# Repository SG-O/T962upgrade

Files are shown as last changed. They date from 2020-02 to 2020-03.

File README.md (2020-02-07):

**WARNING** This is work in progress! Expect everything to be broken!

# T962upgrade | T-962/T-962A controller upgrade #

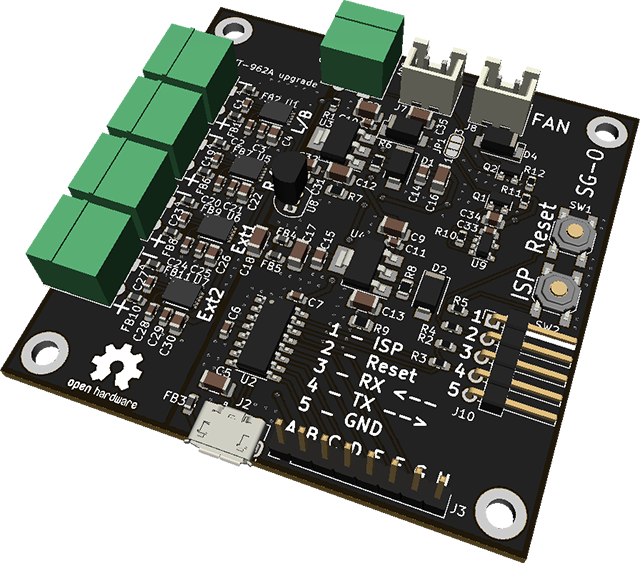
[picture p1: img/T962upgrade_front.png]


## Features ##
### CPU ###
- MAX31850 based K Type thermocouple to single wire converter
- CH340 based USB to UART
- Temperature dependant fan controller

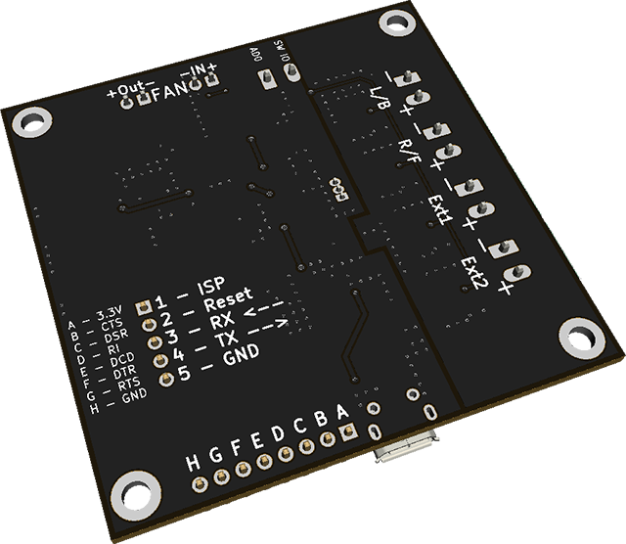
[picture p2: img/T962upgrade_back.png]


### IO ###
- 4 K Type thermocouple to single wire converter
- 1 UART
- 1 USB
- Push buttons for reset and ISP mode

### Power Supply ###
- Dual linear power supplies for digital and analog circuitry

## Software ##
This was designed for the T-962-improvements Firmware developed by UnifiedEngineering: [https://github.com/UnifiedEngineering/T-962-improvements](https://github.com/UnifiedEngineering/T-962-improvements)

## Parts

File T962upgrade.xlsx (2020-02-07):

Component | Description | Part | References | Value | Footprint | Quantity Per PCB | manf# | lcsc# | DNP
1 | Unpolarized capacitor | C | C3 C6 C7 C10 C11 C21 C25 C29 C31 C33 | 100n | C_0603_1608Metric | 10 | CC0603KRX7R9BB104 | C14663
2 | Unpolarized capacitor | C | C1 C2 C19 C20 C23 C24 C27 C28 | 10n | C_0603_1608Metric | 8 | 0603B103K500NT | C57112
3 | Unpolarized capacitor | C | C5 C8 C9 C12 C13 C16 C17 C18 C35 | 10u | C_1206_3216Metric | 9 | CL31A106KBHNNNE | C13585
4 | Unpolarized capacitor | C | C4 C14 C15 C22 C26 C30 C32 C34 | 1u | C_0805_2012Metric | 8 | CL21B105KBFNNNE | C28323
5 | Diode | D | D1 D2 D3 D4 | M7 | D_SMA | 4 | M7 | C95872
6 | Ferrite bead, small symbol | Ferrite_Bead_Small | FB1 FB2 FB3 FB4 FB5 FB6 FB7 FB8 FB9 FB10 FB11 | Ferrite_Bead_Small | L_0603_1608Metric | 11 | BLM18PG121SN1D | C14709
7 | Generic connector, single row, 01x02, script generated (kicad-library-utils/schlib/autogen/connector/) | Conn_01x02 | J7 | Fan In | JST_XH_B2B-XH-A_1x02_P2.50mm_Vertical | 1 | B2B-XH-A(LF)(SN) | C158012
8 | Generic connector, single row, 01x02, script generated (kicad-library-utils/schlib/autogen/connector/) | Conn_01x02 | J8 | Fan Out | JST_XH_B2B-XH-A_1x02_P2.50mm_Vertical | 1 | B2B-XH-A(LF)(SN) | C158012
9 | Generic screw terminal, single row, 01x02, script generated (kicad-library-utils/schlib/autogen/connector/) | Screw_Terminal_01x02 | J1 J4 J5 J6 J9 | K Type | PhoenixContact_MC_1,5_2-G-3.81_1x02_P3.81mm_Horizontal | 5 | WJ15EDGRC-3.81-2P | WJ15EDGK-3.81-2P | C8387 | C8466
10 | Generic connector, single row, 01x05, script generated (kicad-library-utils/schlib/autogen/connector/) | Conn_01x05_Male | J10 | UART | PinHeader_1x05_P2.54mm_Horizontal | 1 | MTB125-1105R1 | C376123
11 | USB Micro Type B connector | USB_B_Micro | J2 | USB_B_Micro | USB_Micro-B_Molex-105017-0001 | 1 | 105017-0001 | C136000
12 | Generic connector, single row, 01x08, script generated (kicad-library-utils/schlib/autogen/connector/) | Conn_01x08_Male | J3 | USB_X | PinHeader_1x08_P2.54mm_Vertical | 1 |  |  | DNP
13 | 3-pole Solder Jumper, pins 1+2 closed/bridged | SolderJumper_3_Bridged12 | JP1 | Jumper_Fan | SolderJumper-3_P1.3mm_Bridged12_RoundedPad1.0x1.5mm_NumberLabels | 1 |  |  | DNP
14 | N-MOSFET transistor, gate/source/drain | Q_NMOS_GSD | Q1 Q2 | 2N7002 | SOT-23 | 2 | 2N7002 | C8545
15 | Resistor | R | R11 R12 | 100k | R_0603_1608Metric | 2 | 0603WAF1003T5E | C25803
16 | Resistor | R | R6 R8 | 237R | R_0805_2012Metric | 2 | ARG05FTC2370N | C218442
17 | Resistor | R | R7 R9 | 383R | R_0805_2012Metric | 2 | ARG05FTC3830 | C218541
18 | Resistor | R | R2 R3 R4 R5 | 470R | R_0603_1608Metric | 4 | 0603WAF4700T5E | C23179
19 | Resistor | R | R1 | 4k7 | R_0603_1608Metric | 1 | 0603WAF4701T5E | C23162
20 | Resistor | R | R10 | 52k3 | R_0603_1608Metric | 1 | ARG03FTC5232 | C218068
21 | Push button switch, generic, two pins | SW_Push | SW1 SW2 | Boot | SW_SPST_SKQG_WithStem | 2 | TS-1187A-C-C-B | C318889
22 | USB serial converter, UART, SOIC-16 | CH340G | U2 | CH340C | SOIC-16_3.9x9.9mm_P1.27mm | 1 | CH340C | C84681
23 | 1-Wire Ambient Temperature Sensor TO-92 | DS18S20 | U8 | DS18S20 | TO-92_Inline | 1 | DS18S20 | C52574
24 | 1A 35V Adjustable Linear Regulator, SOT-89/SOT-223/TO-220/TO-252/TO-263 | LM317_3PinPackage | U3 U4 | LM317_3PinPackage | SOT-223-3_TabPin2 | 2 | LM317DCYR | C51466
25 | Cold-Junction Compensated, 1-Wire Thermocouple-to-Digital Converter | MAX31850KATB | U1 U5 U6 U7 | MAX31850KATB | TDFN-10-1EP_3x4mm_Pitch0.5mm | 4 | MAX31850KATB+ | C476179
26 |  | TMP709 | U9 | TMP709 | SOT-23-5 | 1 | TMP709AIDBVR | C183087

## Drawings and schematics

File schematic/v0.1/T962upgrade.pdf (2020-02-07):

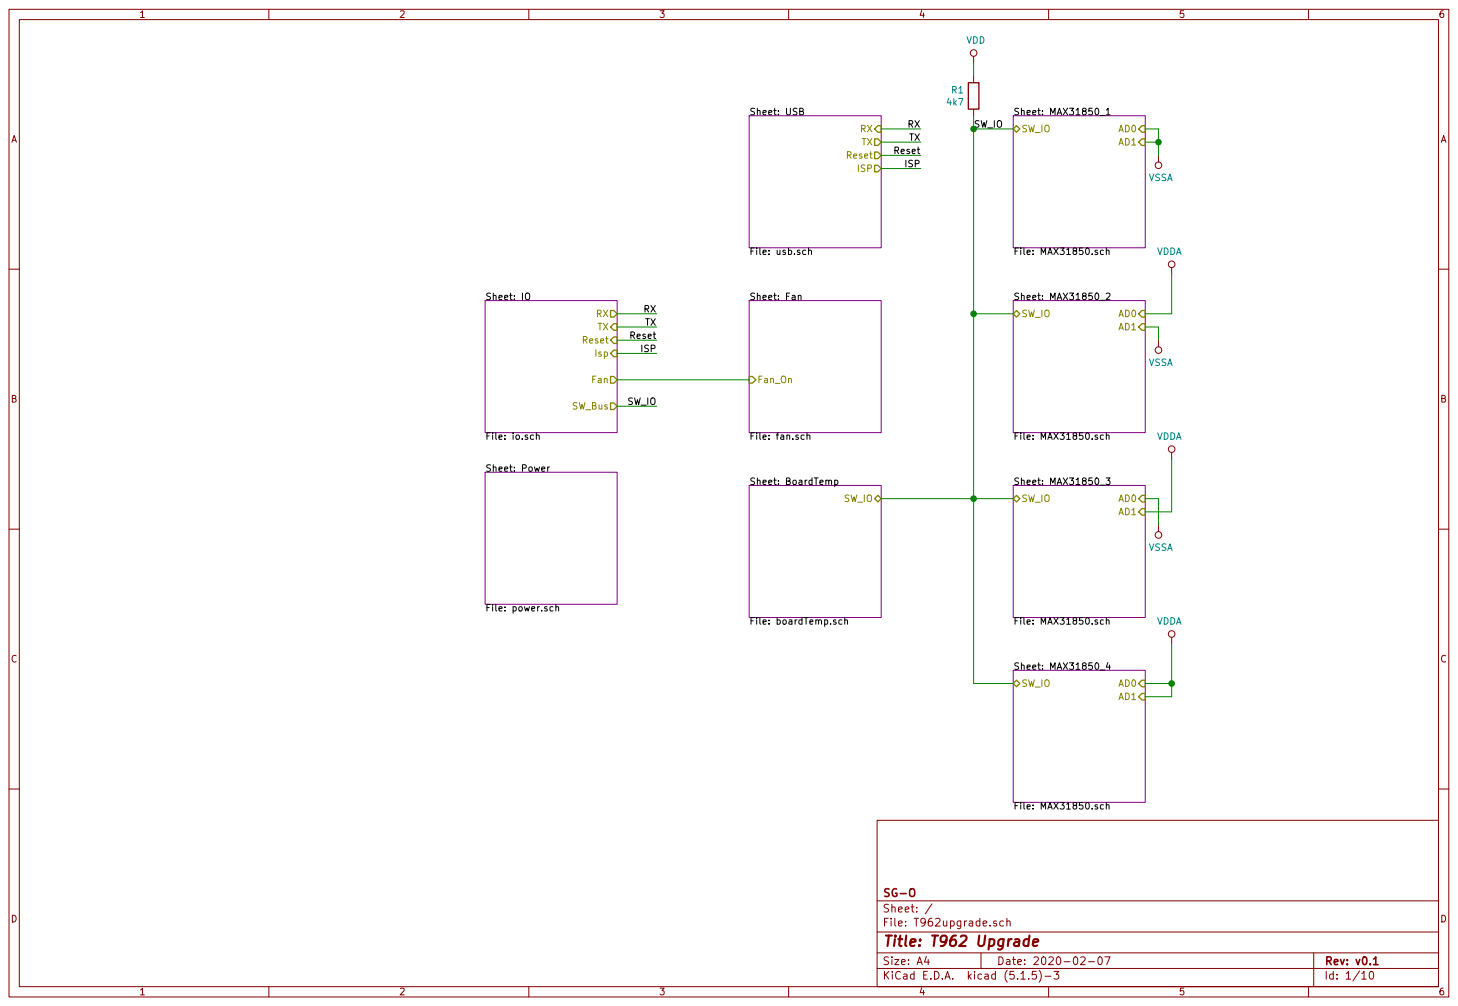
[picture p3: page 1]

Sheet: Fan File: fan.sch Fan_On Sheet: IO

File: T962upgrade.sch Sheet: / SG-O

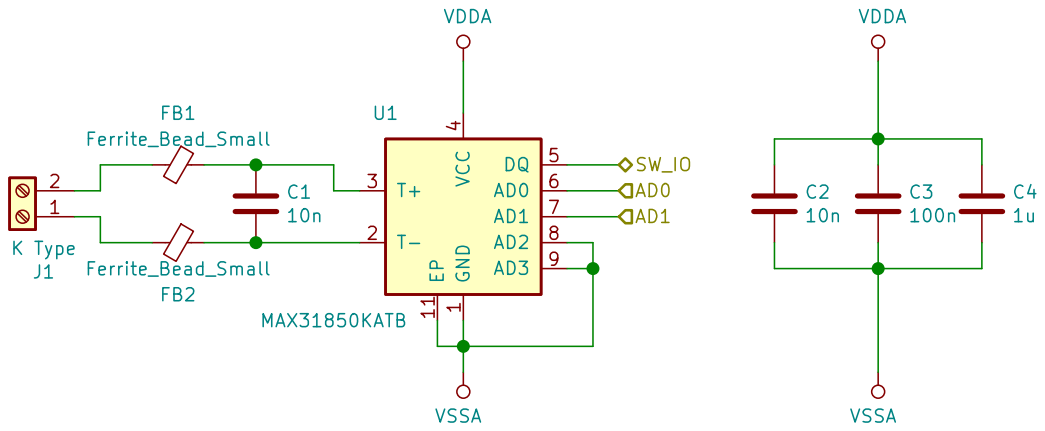
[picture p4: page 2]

File: MAX31850.sch Sheet: /MAX31850_1/ SG-O GND

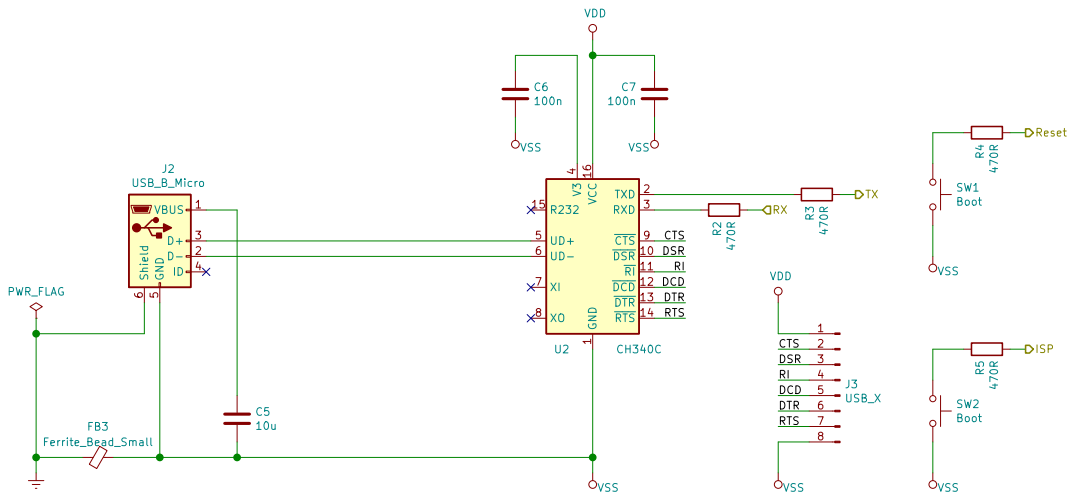
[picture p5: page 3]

1 DSR 10 RI 11 DCD 12 DTR 13 RTS 14 R232 15 VCC 16 TXD 2 RXD 3 V3

4 UD+ 5 UD- 6 XI 7 XO 8 CTS 9 U2 CH340C

File: usb.sch Sheet: /USB/ SG-O

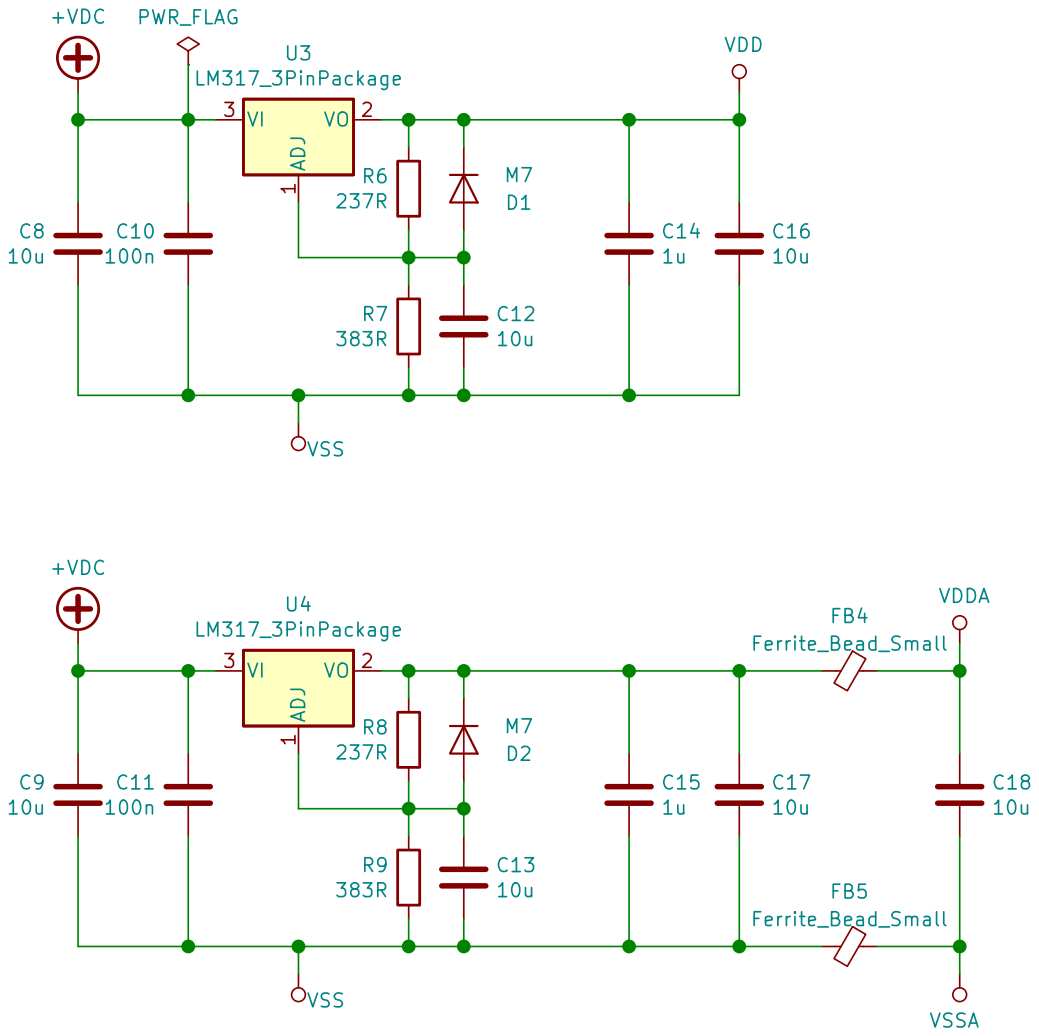
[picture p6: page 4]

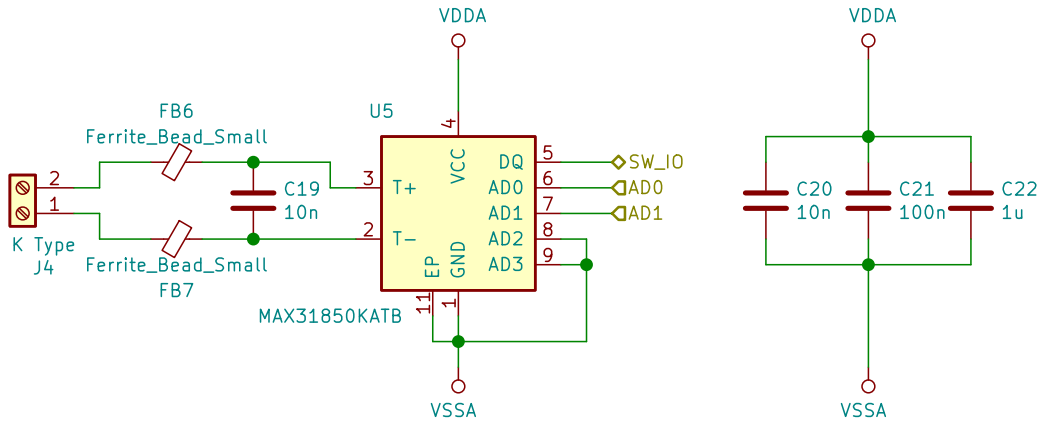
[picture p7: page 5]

File: MAX31850.sch Sheet: /MAX31850_2/ SG-O GND

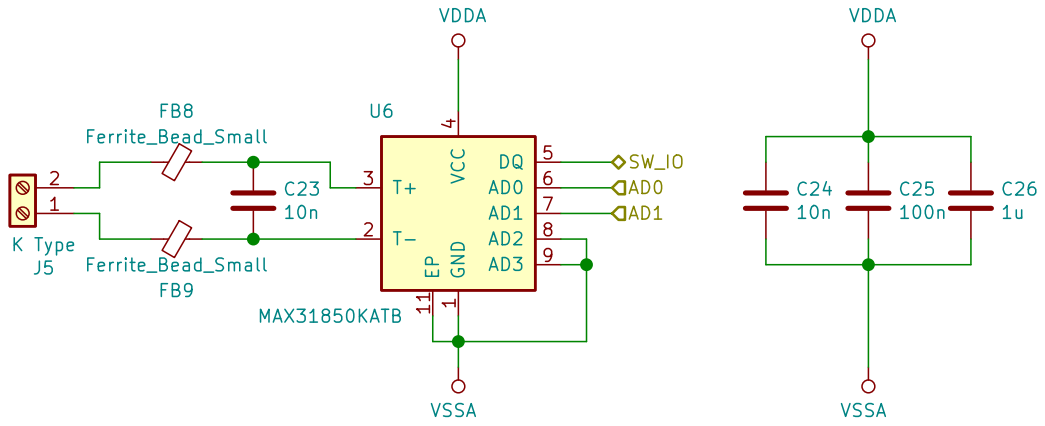
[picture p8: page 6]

File: MAX31850.sch Sheet: /MAX31850_3/ SG-O GND

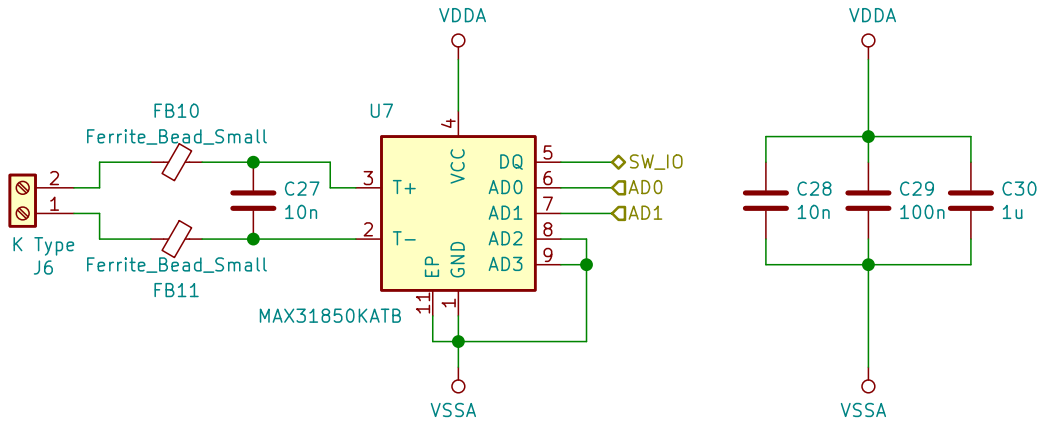
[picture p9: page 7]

File: MAX31850.sch Sheet: /MAX31850_4/ SG-O GND

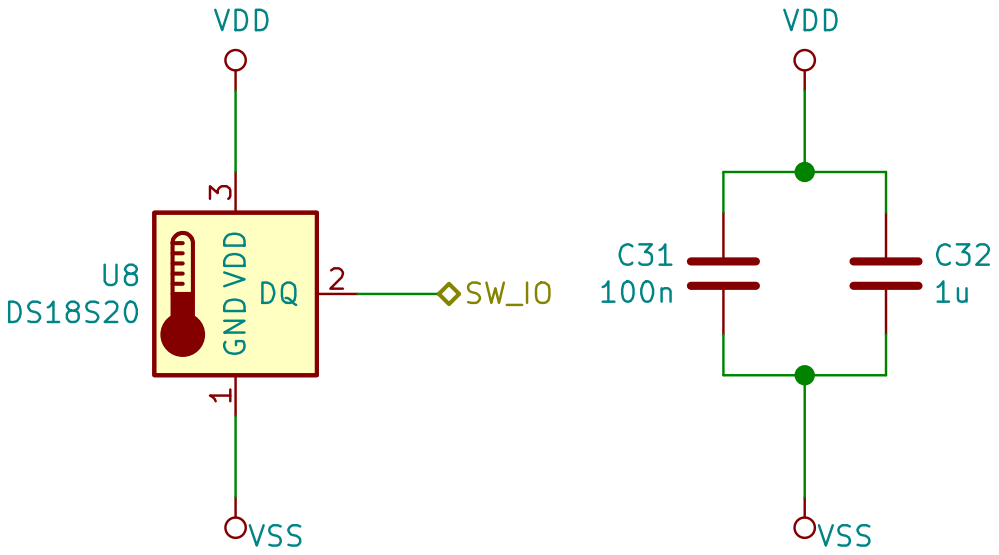
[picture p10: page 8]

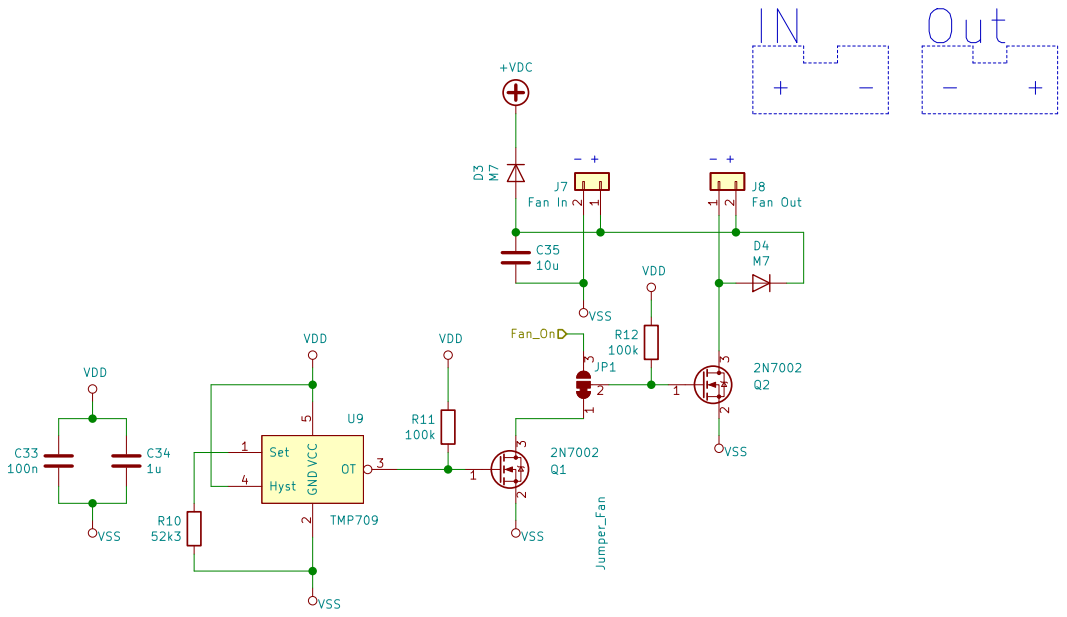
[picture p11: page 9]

File: fan.sch Sheet: /Fan/ SG-O

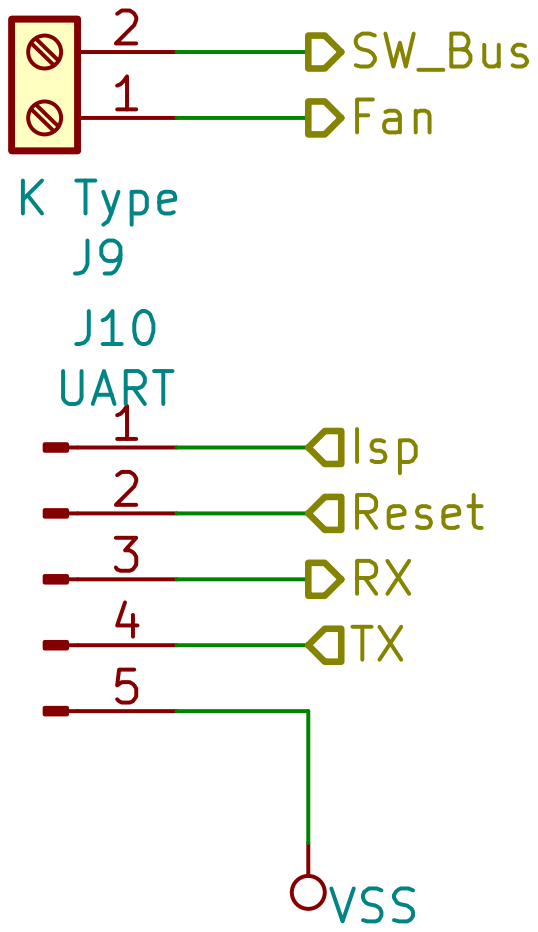
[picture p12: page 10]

File: io.sch Sheet: /IO/ SG-O

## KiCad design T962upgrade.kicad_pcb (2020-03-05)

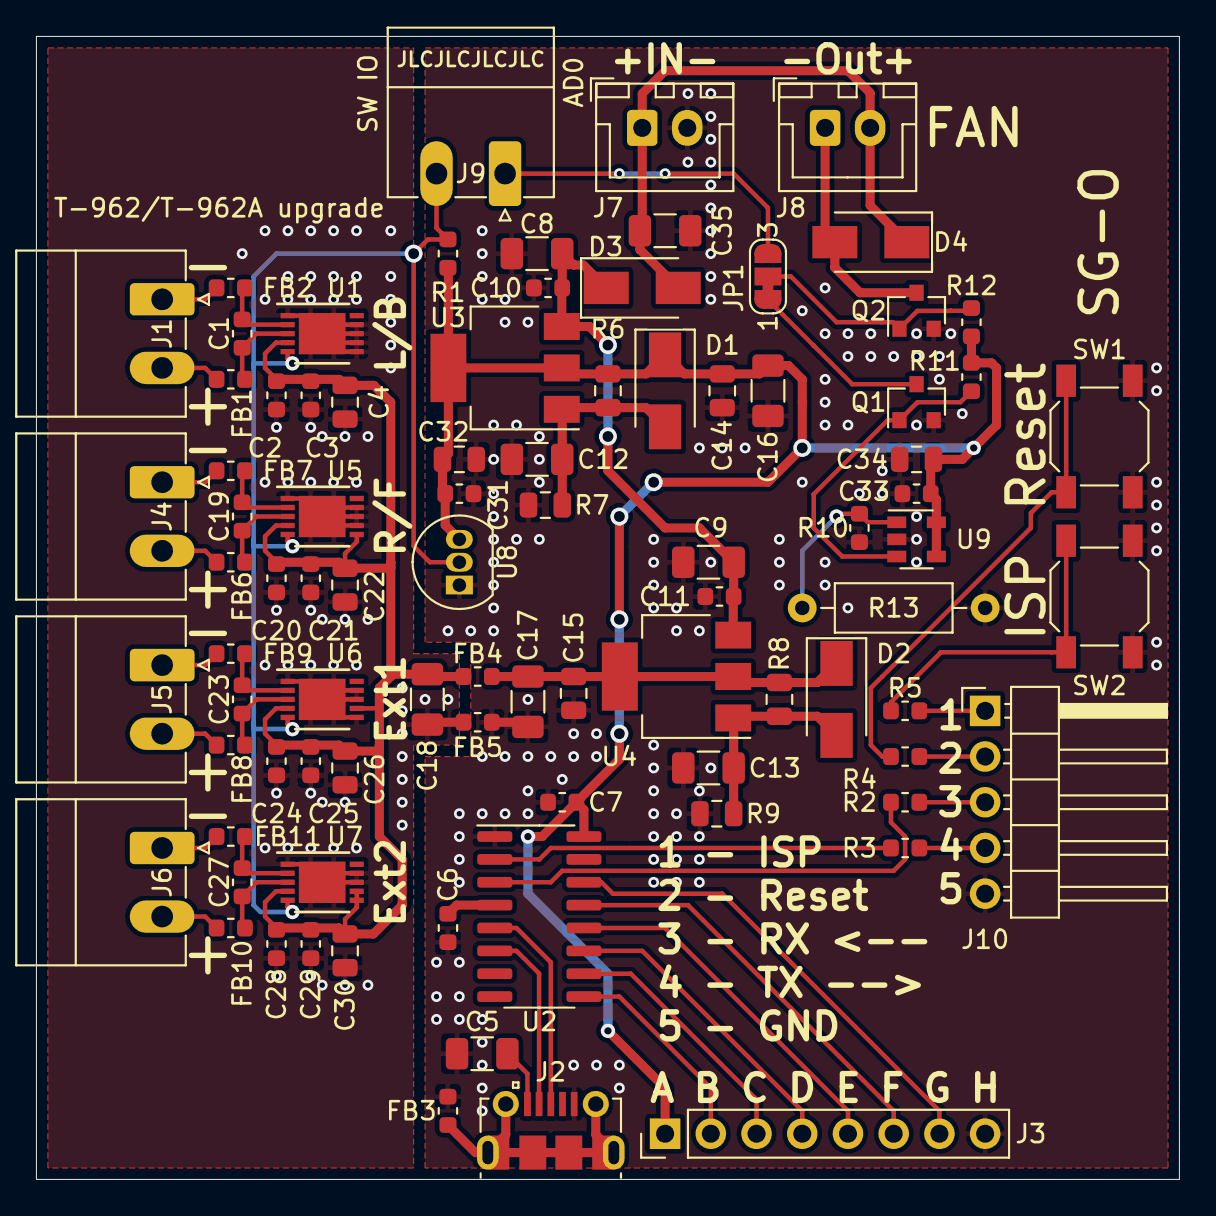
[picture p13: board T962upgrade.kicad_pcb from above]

Board: 2 copper layers, 63.5 x 63.5 mm, 87 parts (0 on the bottom side), 51 nets.

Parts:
C1, C2, C19, C20, C23, C24, C27, C28: 10n; C_0603_1608Metric
C3, C6, C7, C10, C11, C21, C25, C29, C31, C33: 100n; C_0603_1608Metric
C4, C14, C15, C22, C26, C30, C32, C34: 1u; C_0805_2012Metric
C5, C8, C9, C12, C13, C16, C17, C18, C35: 10u; C_1206_3216Metric
D1, D2, D3, D4: M7; D_SMA
FB1, FB2, FB3, FB4, FB5, FB6, FB7, FB8, FB9, FB10, FB11: Ferrite_Bead_Small; L_0603_1608Metric
J1, J4, J5, J6, J9: K Type; PhoenixContact_MC_1,5_2-G-3.81_1x02_P3.81mm_Horizontal
J2: USB_B_Micro; USB_Micro-B_Molex-105017-0001
J3: USB_X; PinHeader_1x08_P2.54mm_Vertical
J7: Fan In; JST_XH_B2B-XH-A_1x02_P2.50mm_Vertical
J8: Fan Out; JST_XH_B2B-XH-A_1x02_P2.50mm_Vertical
J10: UART; PinHeader_1x05_P2.54mm_Horizontal
JP1: Jumper_Fan; SolderJumper-3_P1.3mm_Bridged12_RoundedPad1.0x1.5mm_NumberL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
Q1, Q2: 2N7002; SOT-23
R1: 4k7; R_0603_1608Metric
R2, R3, R4, R5: 470R; R_0603_1608Metric
R6, R8: 237R; R_0805_2012Metric
R7, R9: 383R; R_0805_2012Metric
R10: 62k; R_0603_1608Metric
R11, R12: 100k; R_0603_1608Metric
R13: DNP; R_Axial_DIN0207_L6.3mm_D2.5mm_P10.16mm_Horizontal
SW1, SW2: Boot; SW_SPST_SKQG_WithStem
U1, U5, U6, U7: MAX31850KATB; TDFN-10-1EP_3x4mm_Pitch0.5mm
U2: CH340C; SOIC-16_3.9x9.9mm_P1.27mm
U3, U4: LM317_3PinPackage; SOT-223-3_TabPin2
U8: DS18S20; TO-92_Inline
U9: TMP709; SOT-23-5

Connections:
+VDC: C8.1, C9.1, C10.1, C11.1, D3.1, U3.3, U4.3
/IO/Fan: J9.1, JP1.3
/ISP: J10.1, R5.2
/RX: J10.3, R2.2
/Reset: J10.2, R4.2
/SW_IO: J9.2, R1.2, U1.5, U5.5, U6.5, U7.5, U8.2
/TX: J10.4, R3.2
/USB/CTS: J3.2, U2.9
/USB/DCD: J3.5, U2.12
/USB/DSR: J3.3, U2.10
/USB/DTR: J3.6, U2.13
/USB/RI: J3.4, U2.11
/USB/RTS: J3.7, U2.14
Earth: FB3.2, J2.6
unnamed: C1.1, FB1.1, U1.3
unnamed: C1.2, FB2.1, U1.2
unnamed: C5.1, J2.1
unnamed: C6.1, U2.4
unnamed: C12.1, D1.2, R6.2, R7.1, U3.1
unnamed: C13.1, D2.2, R8.2, R9.1, U4.1
unnamed: C15.1, C17.1, D2.1, FB4.2, R8.1, U4.2
unnamed: C19.1, FB6.1, U5.3
unnamed: C19.2, FB7.1, U5.2
unnamed: C23.1, FB8.1, U6.3
unnamed: C23.2, FB9.1, U6.2
unnamed: C27.1, FB10.1, U7.3
unnamed: C27.2, FB11.1, U7.2
unnamed: C35.1, D3.2, D4.1, J7.1, J8.2
unnamed: D4.2, J8.1, Q2.3
unnamed: FB1.2, J1.2
unnamed: FB2.2, J1.1
unnamed: FB6.2, J4.2
unnamed: FB7.2, J4.1
unnamed: FB8.2, J5.2
unnamed: FB9.2, J5.1
unnamed: FB10.2, J6.2
unnamed: FB11.2, J6.1
unnamed: J2.2, U2.6
unnamed: J2.3, U2.5
unnamed: JP1.1, Q1.3
unnamed: JP1.2, Q2.1, R12.2
unnamed: Q1.1, R11.2, U9.3
unnamed: R2.1, U2.3
unnamed: R3.1, U2.2
unnamed: R4.1, SW1.1
unnamed: R5.1, SW2.1
unnamed: R10.1, R13.1, U9.1
VDD: C7.1, C14.1, C16.1, C31.1, C32.1, C33.1, C34.1, D1.1, J3.1, R1.1, R6.1, R11.1, R12.1, U2.16, U3.2, U8.3, U9.4, U9.5
VDDA: C2.1, C3.1, C4.1, C18.1, C20.1, C21.1, C22.1, C24.1, C25.1, C26.1, C28.1, C29.1, C30.1, FB4.1, U1.4, U5.4, U5.6, U6.4, U6.7, U7.4, U7.6, U7.7
VSS: C5.2, C6.2, C7.2, C8.2, C9.2, C10.2, C11.2, C12.2, C13.2, C14.2, C15.2, C16.2, C17.2, C31.2, C32.2, C33.2, C34.2, C35.2, FB3.1, FB5.2, J2.5, J3.8, J7.2, J10.5, Q1.2, Q2.2, R7.2, R9.2, R10.2, R13.2, SW1.2, SW2.2, U2.1, U8.1, U9.2
VSSA: C2.2, C3.2, C4.2, C18.2, C20.2, C21.2, C22.2, C24.2, C25.2, C26.2, C28.2, C29.2, C30.2, FB5.1, U1.1, U1.6, U1.7, U1.8, U1.9, U1.11, U5.1, U5.7, U5.8, U5.9, U5.11, U6.1, U6.6, U6.8, U6.9, U6.11, U7.1, U7.8, U7.9, U7.11

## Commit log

2020-02-07 Updated gerber
    [T962upgrade-B_Cu.gbl, T962upgrade-B_Mask.gbs, T962upgrade-B_SilkS.gbo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]
2020-03-05 Added optional through hole resistor to set fan switch on temperature.
    [MAX31850.sch, T962upgrade.kicad_pcb, T962upgrade.sch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]

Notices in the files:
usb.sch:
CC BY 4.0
